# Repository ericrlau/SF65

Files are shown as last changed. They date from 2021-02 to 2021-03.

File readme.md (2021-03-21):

# SF65
## A ZMK-Powered BLE Keyboard with visible surface-mount components proudly displayed.

> :warning: **This is an untested project.** Do not use to create your own copy unless you are willing to debug the hardware and/or firmware. 

## Flash bootloader
Bootloader is pre-loaded on assembled pcbs. If you source your own BLE module you will need to unlock the module and flash the bootloader using the Nordic nrf command line tool. 
```
$ nrfjprog --recover --log 
```
```
$ nrfjprog -f nrf52 --program firmware/bootloader/COBO_nrf52840_bootloader-0.3.2-184-g64ea299_s140_6.1.1.hex
```

------------------------------------
## Upload Firmware 

- See ZMK docs for instructions on setting up ZMK and custimizing firmware.  
	* https://zmkfirmware.dev/docs/user-setup/
	* https://zmkfirmware.dev/docs/customization 
- Default *.uf2 files are pre-loaded on assembled pcbs. If you sourced and assembled your own pcb, you can file deafult pre-built firmware here: 
	- https://github.com/ericrlau/COBO-zmk-config/releases

## PCB
- Source files for pcb are in this repo. They are split into three kicad projects:
	- SF65: main pcb, left and right combined. 
	- (ToDo) SF65_Bottom: Bottom cover PCB. 
	- (ToDo) SF65_Plate: Switch plate PCB. 
	- NOTE: KiCad files are created with nightly KiCad 5.99 builds, they are not compatible with current stable release of KiCad 5.
- Bill of materials [Link](https://raw.githack.com/ericrlau/SF65/working/PCB/bom/ibom.html)

## ToDo 
- Test prototypes.
- Create switch plate.
- Create bottom Cover.
- Create bottom foot to angle board.
- Fix silk screen arrow on 1U key to right of spacebar. 

## Images

#### Prototype Build

#### Main PCB
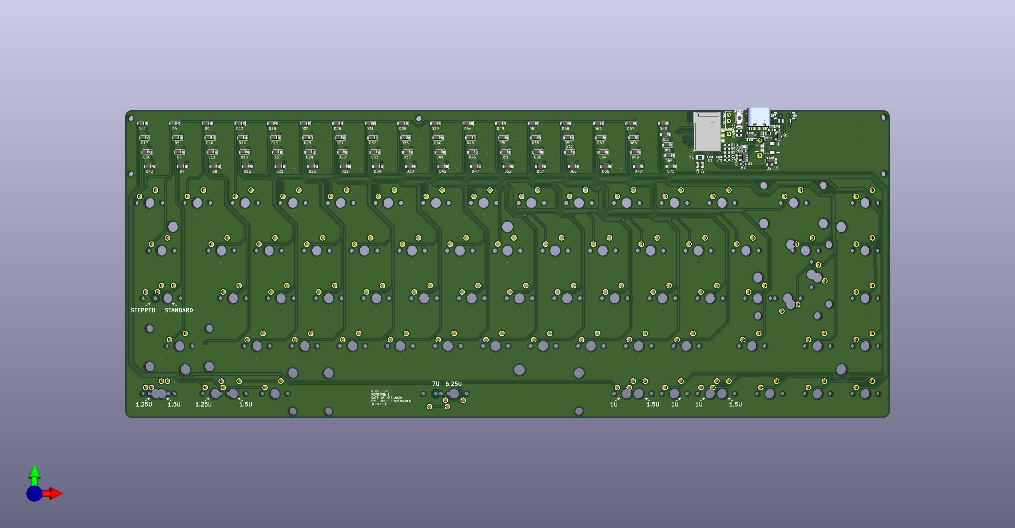
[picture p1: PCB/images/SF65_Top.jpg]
Main TOP

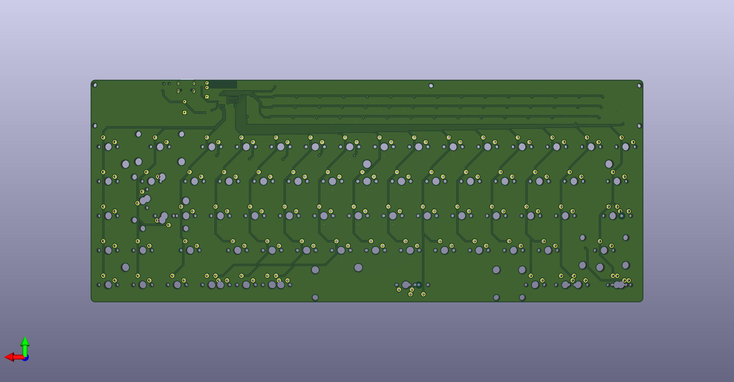
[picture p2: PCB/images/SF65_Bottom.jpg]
Main BOTTOM


#### FR4 Plate

#### Bottom PCB

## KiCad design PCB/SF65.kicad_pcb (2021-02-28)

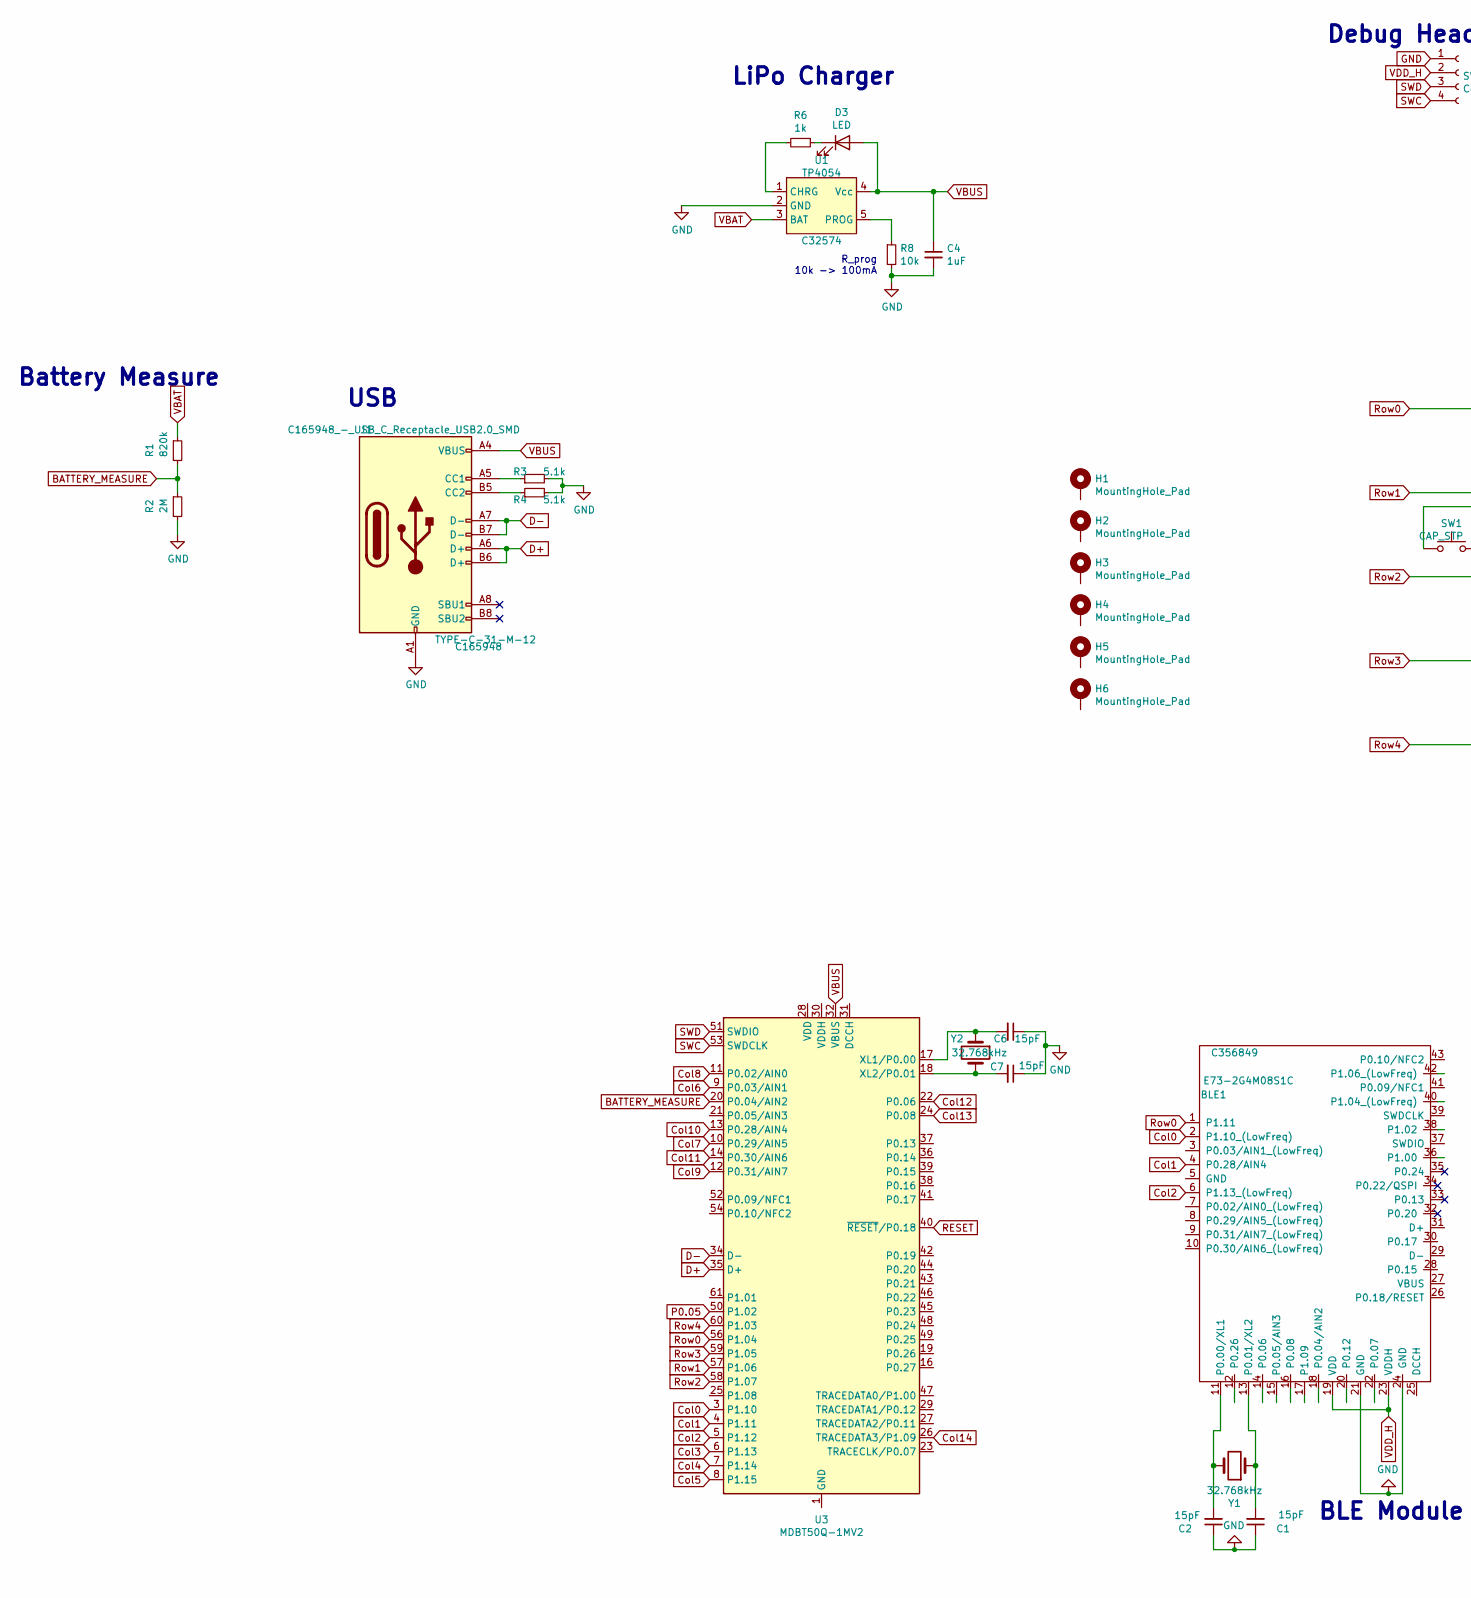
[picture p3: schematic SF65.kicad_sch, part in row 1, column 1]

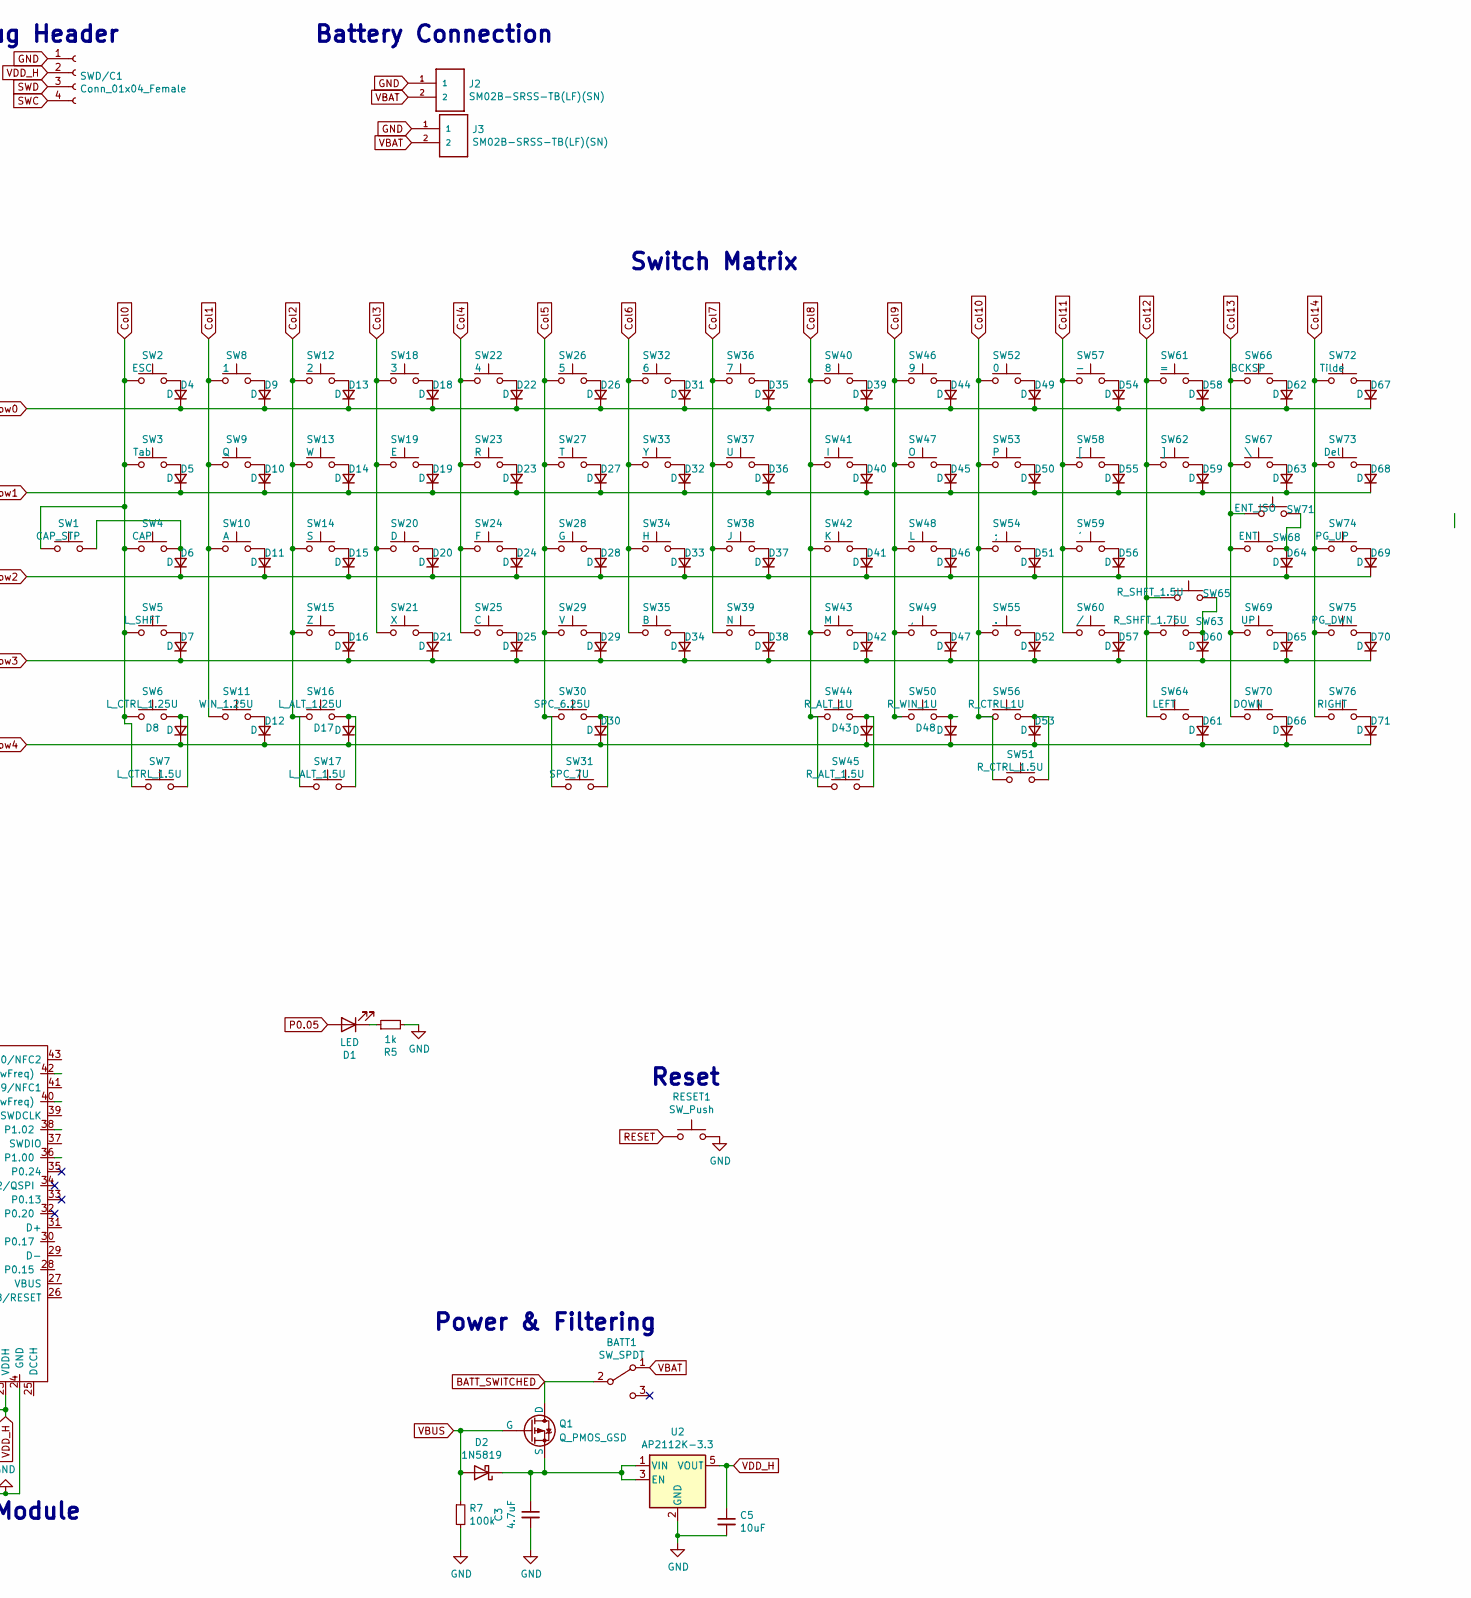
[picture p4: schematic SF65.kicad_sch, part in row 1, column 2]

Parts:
BATT1: SW_SPDT; SW-TH_MSK12C02
BLE1: E73-2G4M08S1C; Manufacturer PN E73-2G4M08S1C; LCSC PN C356849
C1, C2, C6, C7: 15pF; C_0603_1608Metric
C3: 4.7uF; C_0603_1608Metric
C4: 1uF; C_0603_1608Metric
C5: 10uF; C_0603_1608Metric
D1, D3: LED; LED_0603_1608Metric_Pad1.05x0.95mm_HandSolder
D2: 1N5819; D_SOD-323_HandSoldering
D4, D5, D6, D7, D8, D9, D10, D11, D12, D13, D14, D15, D16, D17, D18, D19, D20, D21, D22, D23, D24, D25, D26, D27, D28, D29, D30, D31, D32, D33, D34, D35, D36, D37, D38, D39, D40, D41, D42, D43, D44, D45, D46, D47, D48, D49, D50, D51, D52, D53, D54, D55, D56, D57, D58, D59, D60, D61, D62, D63, D64, D65, D66, D67, D68, D69, D70, D71: D; D_SOD-123
H1, H2, H3, H4, H5, H6: MountingHole_Pad; MountingHole_2.2mm_M2
J1: C165948_-_USB_C_Receptacle_USB2.0_SMD; USB_C_Receptacle_HRO_TYPE-C-31-M-12; Manufacturer PN TYPE-C-31-M-12; LCSC PN C165948
J2: SM02B-SRSS-TB(LF)(SN)
J3: SM02B-SRSS-TB(LF)(SN); PinHeader_1x02_P2.54mm_Vertical
Q1: Q_PMOS_GSD; SOT-23
R1: 820k; R_0603_1608Metric_Pad0.98x0.95mm_HandSolder
R2: 2M; R_0603_1608Metric_Pad0.98x0.95mm_HandSolder
R3, R4: 5.1k; R_0603_1608Metric_Pad0.98x0.95mm_HandSolder
R5, R6: 1k; R_0603_1608Metric_Pad0.98x0.95mm_HandSolder
R7: 100k; R_0603_1608Metric_Pad0.98x0.95mm_HandSolder
R8: 10k; R_0603_1608Metric_Pad0.98x0.95mm_HandSolder
RESET1: SW_Push; SW_SPST_B3U-1000P
SW1: CAP_STP; MX_1.75U_STEPPEDCAPS
SW2: ESC; SW_Cherry_MX_1.00u_PCB
SW3: Tab; SW_Cherry_MX_1.50u_PCB
SW4: CAP; SW_Cherry_MX_1.75u_PCB
SW5: L_SHFT; SW_Cherry_MX_2.25u_PCB
SW6: L_CTRL_1.25U; SW_Cherry_MX_1.25u_PCB
SW7: L_CTRL_1.5U; SW_Cherry_MX_1.50u_PCB
SW8: 1; SW_Cherry_MX_1.00u_PCB
SW9: Q; SW_Cherry_MX_1.00u_PCB
SW10: A; SW_Cherry_MX_1.00u_PCB
SW11: WIN_1.25U; SW_Cherry_MX_1.25u_PCB
SW12: 2; SW_Cherry_MX_1.00u_PCB
SW13: W; SW_Cherry_MX_1.00u_PCB
SW14: S; SW_Cherry_MX_1.00u_PCB
SW15: Z; SW_Cherry_MX_1.00u_PCB
SW16: L_ALT_1.25U; SW_Cherry_MX_1.25u_PCB
SW17: L_ALT_1.5U; SW_Cherry_MX_1.50u_PCB
SW18: 3; SW_Cherry_MX_1.00u_PCB
SW19: E; SW_Cherry_MX_1.00u_PCB
SW20: D; SW_Cherry_MX_1.00u_PCB
SW21: X; SW_Cherry_MX_1.00u_PCB
SW22: 4; SW_Cherry_MX_1.00u_PCB
SW23: R; SW_Cherry_MX_1.00u_PCB
SW24: F; SW_Cherry_MX_1.00u_PCB
SW25: C; SW_Cherry_MX_1.00u_PCB
SW26: 5; SW_Cherry_MX_1.00u_PCB
SW27: T; SW_Cherry_MX_1.00u_PCB
SW28: G; SW_Cherry_MX_1.00u_PCB
SW29: V; SW_Cherry_MX_1.00u_PCB
SW30: SPC_6.25U; SW_Cherry_MX_6.25u_PCB
SW31: SPC_7U; MX_7U
SW32: 6; SW_Cherry_MX_1.00u_PCB
SW33: Y; SW_Cherry_MX_1.00u_PCB
SW34: H; SW_Cherry_MX_1.00u_PCB
SW35: B; SW_Cherry_MX_1.00u_PCB
SW36: 7; SW_Cherry_MX_1.00u_PCB
SW37: U; SW_Cherry_MX_1.00u_PCB
SW38: J; SW_Cherry_MX_1.00u_PCB
SW39: N; SW_Cherry_MX_1.00u_PCB
SW40: 8; SW_Cherry_MX_1.00u_PCB
SW41: I; SW_Cherry_MX_1.00u_PCB
SW42: K; SW_Cherry_MX_1.00u_PCB
SW43: M; SW_Cherry_MX_1.00u_PCB
SW44: R_ALT_1U; SW_Cherry_MX_1.00u_PCB
SW45: R_ALT_1.5U; SW_Cherry_MX_1.50u_PCB
SW46: 9; SW_Cherry_MX_1.00u_PCB
SW47: O; SW_Cherry_MX_1.00u_PCB
SW48: L; SW_Cherry_MX_1.00u_PCB
SW49: ,; SW_Cherry_MX_1.00u_PCB
SW50: R_WIN_1U; SW_Cherry_MX_1.00u_PCB
SW51: R_CTRL_1.5U; SW_Cherry_MX_1.50u_PCB
SW52: 0; SW_Cherry_MX_1.00u_PCB
SW53: P; SW_Cherry_MX_1.00u_PCB
SW54: ;; SW_Cherry_MX_1.00u_PCB
SW55: .; SW_Cherry_MX_1.00u_PCB
SW56: R_CTRL_1U; SW_Cherry_MX_1.00u_PCB
SW57: -; SW_Cherry_MX_1.00u_PCB
SW58: [; SW_Cherry_MX_1.00u_PCB
SW59: '; SW_Cherry_MX_1.00u_PCB
SW60: /; SW_Cherry_MX_1.00u_PCB
SW61: =; SW_Cherry_MX_1.00u_PCB
SW62: ]; SW_Cherry_MX_1.00u_PCB
SW63: R_SHFT_1.75U; SW_Cherry_MX_1.75u_PCB
SW64: LEFT; SW_Cherry_MX_1.00u_PCB
SW65: R_SHFT_1.5U; SW_Cherry_MX_1.50u_PCB
SW66: BCKSP; SW_Cherry_MX_2.00u_PCB
SW67: \; SW_Cherry_MX_1.50u_PCB
SW68: ENT; SW_Cherry_MX_2.25u_PCB
SW69: UP; SW_Cherry_MX_1.00u_PCB
SW70: DOWN; SW_Cherry_MX_1.00u_PCB
SW71: ENT_ISO; SW_Cherry_MX_ISOEnter_PCB
SW72: Tilde; SW_Cherry_MX_1.00u_PCB
SW73: Del; SW_Cherry_MX_1.00u_PCB
SW74: PG_UP; SW_Cherry_MX_1.00u_PCB
SW75: PG_DWN; SW_Cherry_MX_1.00u_PCB
SW76: RIGHT; SW_Cherry_MX_1.00u_PCB
SWD/C1: Conn_01x04_Female; PinHeader_1x04_P2.54mm_Vertical
U1: TP4054; SOT-23-5; Manufacturer PN TP4054; LCSC PN C32574
U2: AP2112K-3.3; SOT-23-5
U3: MDBT50Q-1MV2; Raytac_MDBT50Q
Y1, Y2: 32.768kHz; FC-135R_L3.2-W1.5

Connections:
BATTERY_MEASURE: R1.2, R2.1, U3.20 (P0.04/AIN2)
BATT_SWITCHED: BATT1.2 (B), Q1.3 (D)
Col0: BLE1.2 (P1.10_(LowFreq)), SW1.1, SW2.1, SW3.1, SW4.1, SW5.1, SW6.1, SW7.1, U3.3 (P1.10)
Col1: BLE1.4 (P0.28/AIN4), SW8.1, SW9.1, SW10.1, SW11.1, U3.4 (P1.11)
Col2: BLE1.6 (P1.13_(LowFreq)), SW12.1, SW13.1, SW14.1, SW15.1, SW16.1, SW17.1, U3.5 (P1.12)
Col3: SW18.1, SW19.1, SW20.1, SW21.1, U3.6 (P1.13)
Col4: SW22.1, SW23.1, SW24.1, SW25.1, U3.7 (P1.14)
Col5: SW26.1, SW27.1, SW28.1, SW29.1, SW30.1, SW31.1, U3.8 (P1.15)
Col6: SW32.1, SW33.1, SW34.1, SW35.1, U3.9 (P0.03/AIN1)
Col7: SW36.1, SW37.1, SW38.1, SW39.1, U3.10 (P0.29/AIN5)
Col8: SW40.1, SW41.1, SW42.1, SW43.1, SW44.1, SW45.1, U3.11 (P0.02/AIN0)
Col9: SW46.1, SW47.1, SW48.1, SW49.1, SW50.1, U3.12 (P0.31/AIN7)
Col10: SW51.1, SW52.1, SW53.1, SW54.1, SW55.1, SW56.1, U3.13 (P0.28/AIN4)
Col11: SW57.1, SW58.1, SW59.1, SW60.1, U3.14 (P0.30/AIN6)
Col12: SW61.1, SW62.1, SW63.1, SW64.1, SW65.1, U3.22 (P0.06)
Col13: SW66.1, SW67.1, SW68.1, SW69.1, SW70.1, SW71.1, U3.24 (P0.08)
Col14: SW72.1, SW73.1, SW74.1, SW75.1, SW76.1, U3.26 (TRACEDATA3/P1.09)
D+: J1.A6 (D+), J1.B6 (D+), U3.35 (D+); also elsewhere on the board
D-: J1.A7 (D-), J1.B7 (D-), U3.34 (D-); also elsewhere on the board
GND: BLE1.21 (GND), BLE1.24 (GND), C1.1, C2.1, C3.2, C4.2, C5.2, C6.1, C7.1, J1.A1 (GND), J1.A12 (GND), J1.B1 (GND), J1.B12 (GND), J2.1, J3.1, R2.2, R3.2, R4.2, R5.2, R7.2, R8.2, RESET1.2, SWD/C1.1, U1.2 (GND), U2.2 (GND); also elsewhere on the board
unnamed: BLE1.11 (P0.00/XL1), C2.2, Y1.2
unnamed: BLE1.13 (P0.01/XL2), C1.2, Y1.1
unnamed: C3.1, D2.1 (K), Q1.2 (S), U2.1 (VIN), U2.3 (EN)
unnamed: C6.2, U3.17 (XL1/P0.00), Y2.1
unnamed: C7.2, U3.18 (XL2/P0.01), Y2.2
unnamed: D1.1 (K), R5.1
unnamed: D3.1 (K), R6.1
unnamed: D4.2 (A), SW2.2
unnamed: D5.2 (A), SW3.2
unnamed: D6.2 (A), SW1.2, SW4.2
unnamed: D7.2 (A), SW5.2
unnamed: D8.2 (A), SW6.2, SW7.2
unnamed: D9.2 (A), SW8.2
unnamed: D10.2 (A), SW9.2
unnamed: D11.2 (A), SW10.2
unnamed: D12.2 (A), SW11.2
unnamed: D13.2 (A), SW12.2
unnamed: D14.2 (A), SW13.2
unnamed: D15.2 (A), SW14.2
unnamed: D16.2 (A), SW15.2
unnamed: D17.2 (A), SW16.2, SW17.2
unnamed: D18.2 (A), SW18.2
unnamed: D19.2 (A), SW19.2
unnamed: D20.2 (A), SW20.2
unnamed: D21.2 (A), SW21.2
unnamed: D22.2 (A), SW22.2
unnamed: D23.2 (A), SW23.2
unnamed: D24.2 (A), SW24.2
unnamed: D25.2 (A), SW25.2
unnamed: D26.2 (A), SW26.2
unnamed: D27.2 (A), SW27.2
unnamed: D28.2 (A), SW28.2
unnamed: D29.2 (A), SW29.2
unnamed: D30.2 (A), SW30.2, SW31.2
unnamed: D31.2 (A), SW32.2
unnamed: D32.2 (A), SW33.2
unnamed: D33.2 (A), SW34.2
unnamed: D34.2 (A), SW35.2
unnamed: D35.2 (A), SW36.2
unnamed: D36.2 (A), SW37.2
unnamed: D37.2 (A), SW38.2
unnamed: D38.2 (A), SW39.2
unnamed: D39.2 (A), SW40.2
unnamed: D40.2 (A), SW41.2
unnamed: D41.2 (A), SW42.2
unnamed: D42.2 (A), SW43.2
unnamed: D43.2 (A), SW44.2, SW45.2
unnamed: D44.2 (A), SW46.2
unnamed: D45.2 (A), SW47.2
unnamed: D46.2 (A), SW48.2
unnamed: D47.2 (A), SW49.2
unnamed: D48.2 (A), SW50.2
unnamed: D49.2 (A), SW52.2
unnamed: D50.2 (A), SW53.2
unnamed: D51.2 (A), SW54.2
unnamed: D52.2 (A), SW55.2
unnamed: D53.2 (A), SW51.2, SW56.2
unnamed: D54.2 (A), SW57.2
unnamed: D55.2 (A), SW58.2
unnamed: D56.2 (A), SW59.2
unnamed: D57.2 (A), SW60.2
unnamed: D58.2 (A), SW61.2
unnamed: D59.2 (A), SW62.2
unnamed: D60.2 (A), SW63.2, SW65.2
unnamed: D61.2 (A), SW64.2
unnamed: D62.2 (A), SW66.2
unnamed: D63.2 (A), SW67.2
unnamed: D64.2 (A), SW68.2, SW71.2
unnamed: D65.2 (A), SW69.2
unnamed: D66.2 (A), SW70.2
unnamed: D67.2 (A), SW72.2
unnamed: D68.2 (A), SW73.2
unnamed: D69.2 (A), SW74.2
unnamed: D70.2 (A), SW75.2
unnamed: D71.2 (A), SW76.2
unnamed 95: J1.A5 (CC1), R3.1; also elsewhere on the board
unnamed 96: J1.B5 (CC2), R4.1; also elsewhere on the board
unnamed: R6.2, U1.1 (CHRG)
unnamed: R8.1, U1.5 (PROG)
unnamed: U3.1 (GND), U3.2 (GND), U3.15 (GND), U3.33 (GND), U3.55 (GND)
P0.05: D1.2 (A), U3.50 (P1.02)
RESET: RESET1.1, U3.40 (~RESET~/P0.18); also elsewhere on the board
Row0: BLE1.1 (P1.11), D4.1 (K), D9.1 (K), D13.1 (K), D18.1 (K), D22.1 (K), D26.1 (K), D31.1 (K), D35.1 (K), D39.1 (K), D44.1 (K), D49.1 (K), D54.1 (K), D58.1 (K), D62.1 (K), D67.1 (K), U3.56 (P1.04)
Row1: D5.1 (K), D10.1 (K), D14.1 (K), D19.1 (K), D23.1 (K), D27.1 (K), D32.1 (K), D36.1 (K), D40.1 (K), D45.1 (K), D50.1 (K), D55.1 (K), D59.1 (K), D63.1 (K), D68.1 (K), U3.57 (P1.06)
Row2: D6.1 (K), D11.1 (K), D15.1 (K), D20.1 (K), D24.1 (K), D28.1 (K), D33.1 (K), D37.1 (K), D41.1 (K), D46.1 (K), D51.1 (K), D56.1 (K), D64.1 (K), D69.1 (K), U3.58 (P1.07)
Row3: D7.1 (K), D16.1 (K), D21.1 (K), D25.1 (K), D29.1 (K), D34.1 (K), D38.1 (K), D42.1 (K), D47.1 (K), D52.1 (K), D57.1 (K), D60.1 (K), D65.1 (K), D70.1 (K), U3.59 (P1.05)
Row4: D8.1 (K), D12.1 (K), D17.1 (K), D30.1 (K), D43.1 (K), D48.1 (K), D53.1 (K), D61.1 (K), D66.1 (K), D71.1 (K), U3.60 (P1.03)
SWC: SWD/C1.4, U3.53 (SWDCLK); also elsewhere on the board
SWD: SWD/C1.3, U3.51 (SWDIO); also elsewhere on the board
VBAT: BATT1.1 (A), J2.2, J3.2, R1.1, U1.3 (BAT)
VBUS: C4.1, D2.2 (A), D3.2 (A), J1.A4 (VBUS), J1.A9 (VBUS), J1.B4 (VBUS), J1.B9 (VBUS), Q1.1 (G), R7.1, U1.4 (Vcc), U3.32 (VBUS); also elsewhere on the board
VDD_H: BLE1.19 (VDD), BLE1.23 (VDDH), C5.1, SWD/C1.2, U2.5 (VOUT); also elsewhere on the board

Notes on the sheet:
Battery Measure
USB
LiPo Charger
R_prog 10k -> 100mA
Debug Header
BLE Module
Battery Connection
Power & Filtering
Switch Matrix
Reset

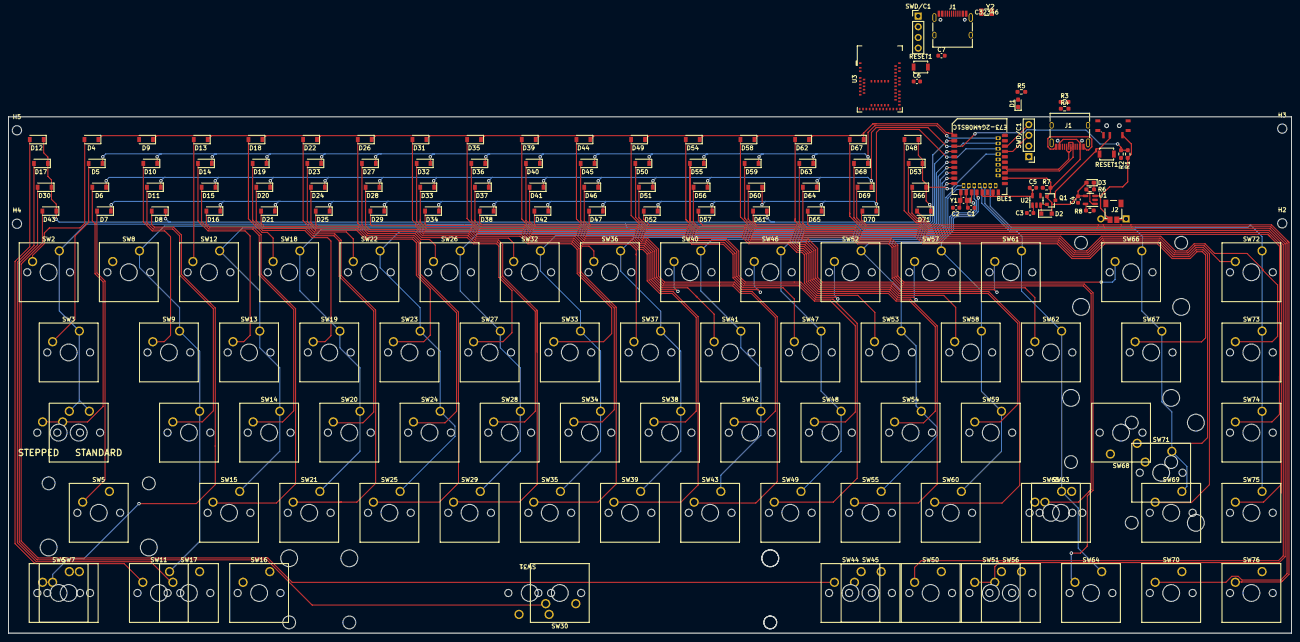
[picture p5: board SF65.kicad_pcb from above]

Board: 2 copper layers, 304.8 x 122.6 mm, 184 parts (0 on the bottom side), 112 nets.

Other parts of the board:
J1#2: C165948_-_USB_C_Receptacle_USB2.0_SMD; USB_C_Receptacle_HRO_TYPE-C-31-M-12
RESET1#2: SW_Push; SW_SPST_B3U-1000P
SWD/C1#2: Conn_01x04_Female; PinHeader_1x04_P2.54mm_Vertical

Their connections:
D+: J1#2.A6 (D+), J1#2.B6 (D+); also elsewhere on the board
D-: J1#2.A7 (D-), J1#2.B7 (D-); also elsewhere on the board
GND: J1#2.A1 (GND), J1#2.A12 (GND), J1#2.B1 (GND), J1#2.B12 (GND), RESET1#2.2, SWD/C1#2.1; also elsewhere on the board
unnamed 95: J1#2.A5 (CC1); also elsewhere on the board
unnamed 96: J1#2.B5 (CC2); also elsewhere on the board
RESET: RESET1#2.1; also elsewhere on the board
SWC: SWD/C1#2.4; also elsewhere on the board
SWD: SWD/C1#2.3; also elsewhere on the board
VBUS: J1#2.A4 (VBUS), J1#2.A9 (VBUS), J1#2.B4 (VBUS), J1#2.B9 (VBUS); also elsewhere on the board
VDD_H: SWD/C1#2.2; also elsewhere on the board

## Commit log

2021-02-03 diodes placed
    [SF65.kicad_pcb]
2021-02-07 working on routing, not complete
    [SF65.kicad_pcb, SF65.kicad_sch]
2021-02-28 about to swap in raytac module
    [SF65.kicad_pcb, SF65.kicad_sch]
2021-03-07 order SF65 samples from JLC
    [SF65-B_Mask.gbr, SF65-B_Paste.gbr, SF65-B_Silkscreen.gbr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]
2021-03-21 cleanup and readme
    [SF65-B_Mask.gbr, SF65-B_Paste.gbr, SF65-B_Silkscreen.gbr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]
2021-04-18 starting to make v2 edits, not finished
    [SF65.kicad_sch]
